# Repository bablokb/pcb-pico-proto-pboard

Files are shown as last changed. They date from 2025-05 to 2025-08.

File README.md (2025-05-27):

Protoyping Board for the Raspberry Pi Pico
==========================================

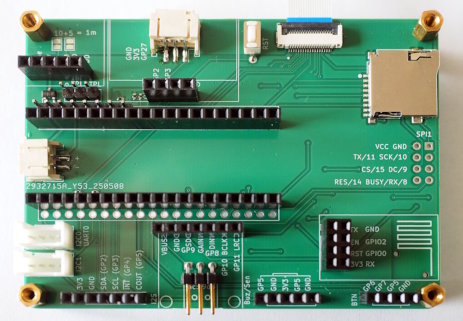
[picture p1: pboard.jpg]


This is a small prototyping board for the Pico. Besides
the normal 2x20 through holes for the Pico, the PCB also
provides additional sockets for the connection of peripherals.

The idea of this board is to simplify software-development
for standard breakouts, because it provides sockets for
these components and thus no wiring is necessary.

Some supported components:

  - Mini-I2C-OLED
  - EYESPI (typically for SPI-displays)
  - 2x Grove (I2C0/UART0 and I2C1)
  - ESP-01S or Lilygo T-01 C3
  - passive buzzer
  - MAX98357A (I2S mono-amplifier)
  - button-breakout (3xbutton, 1xGND)
  - RTC-socket (for this PCB: <https://github.com/bablokb/pcb-pico-pcf8563.git>)
  - Adafruit TPL5110 power-switch breakout
  - SD-card socket (on-board)
  - JST-PH2 battery connector
  - JST-PH3 connector (ADC)

Note that some components share pins, so it is *not possible* to use
all components in parallel! See [pinout](./pins.md) for details.

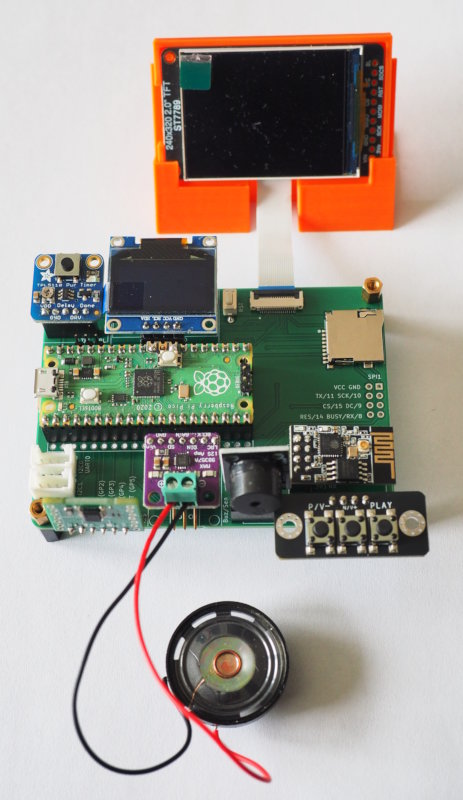
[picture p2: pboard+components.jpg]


Ready to use Gerber, BOM and POS files for JLCPCB are in the subdirectory
"production_files".

Schematic
---------

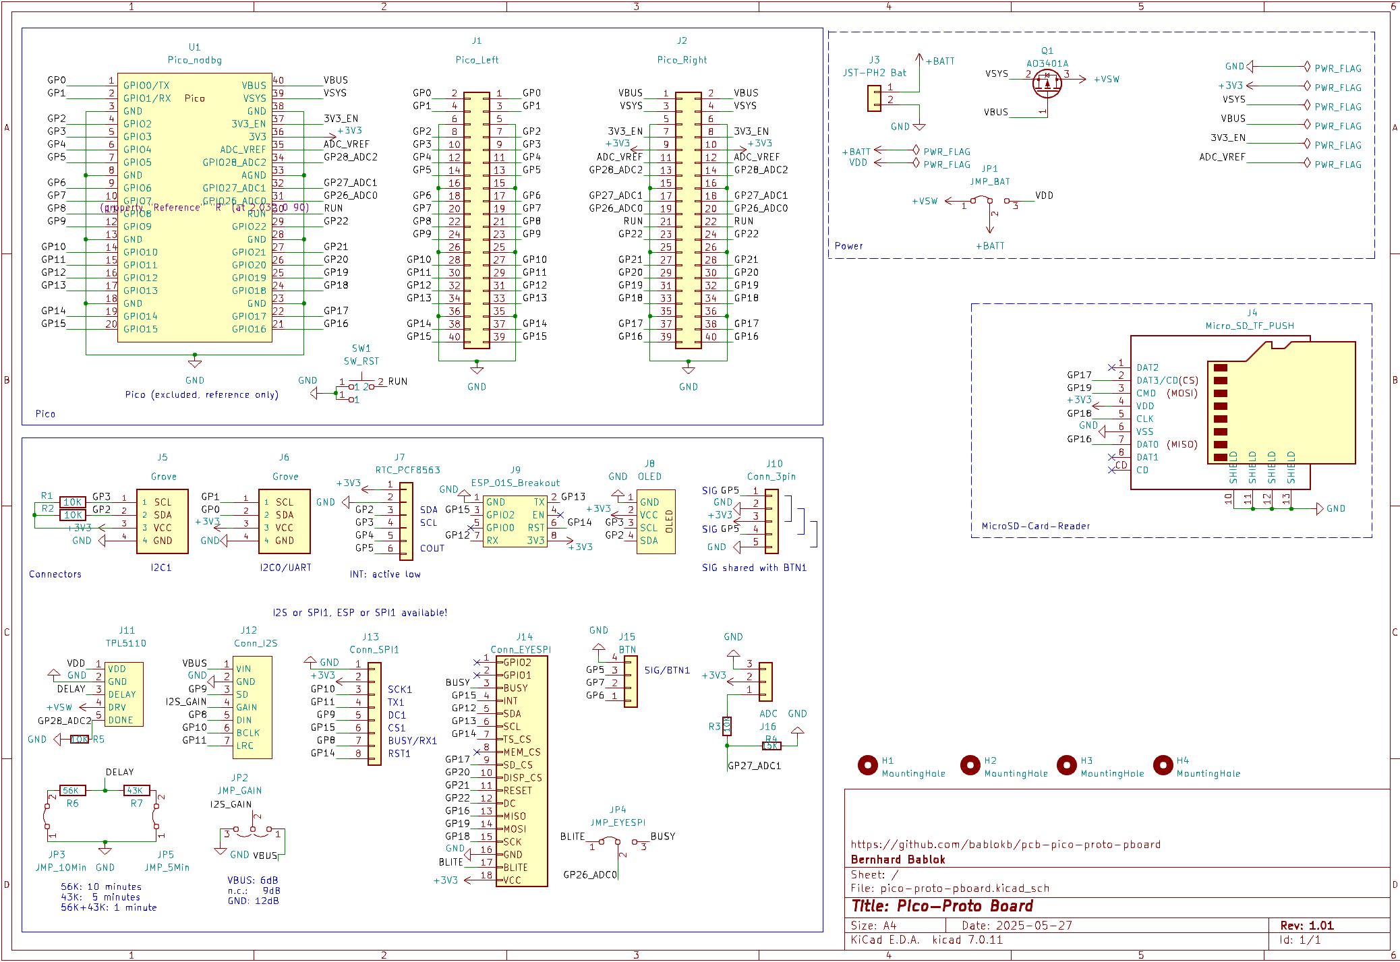
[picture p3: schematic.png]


Layout
------

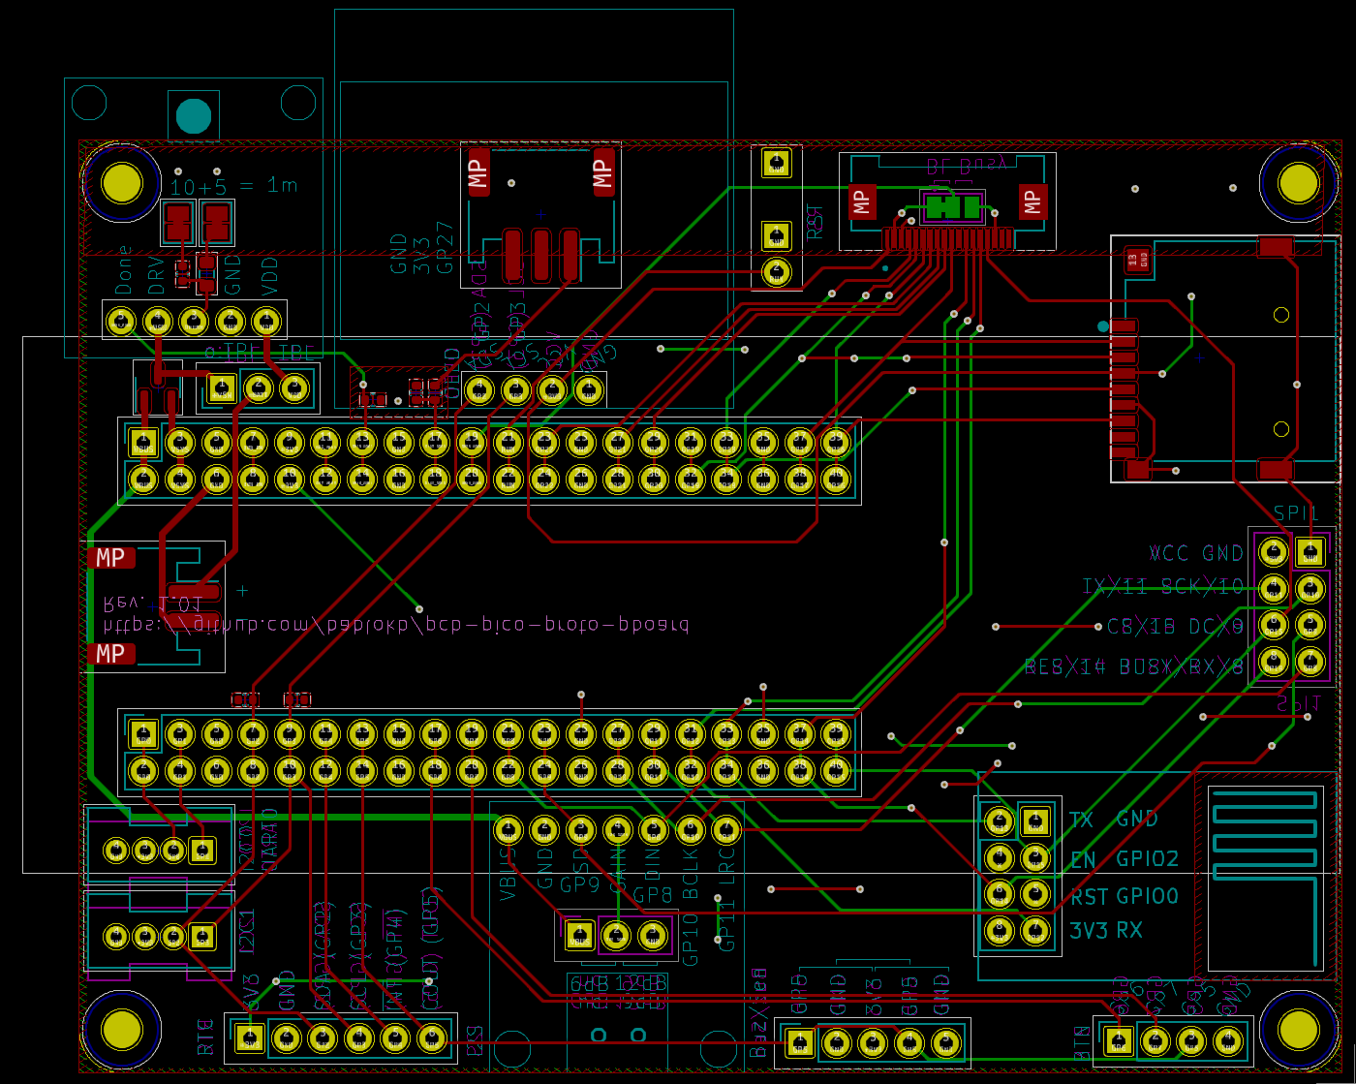
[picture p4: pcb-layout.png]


3D-Views
--------

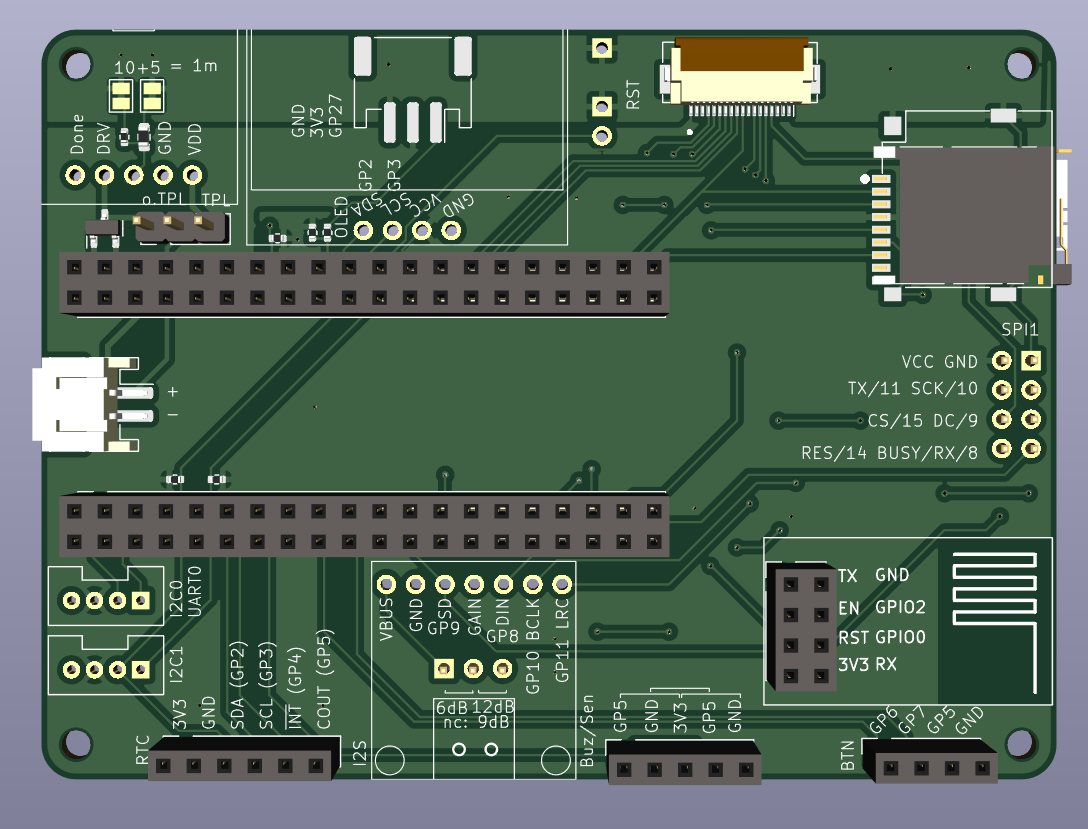
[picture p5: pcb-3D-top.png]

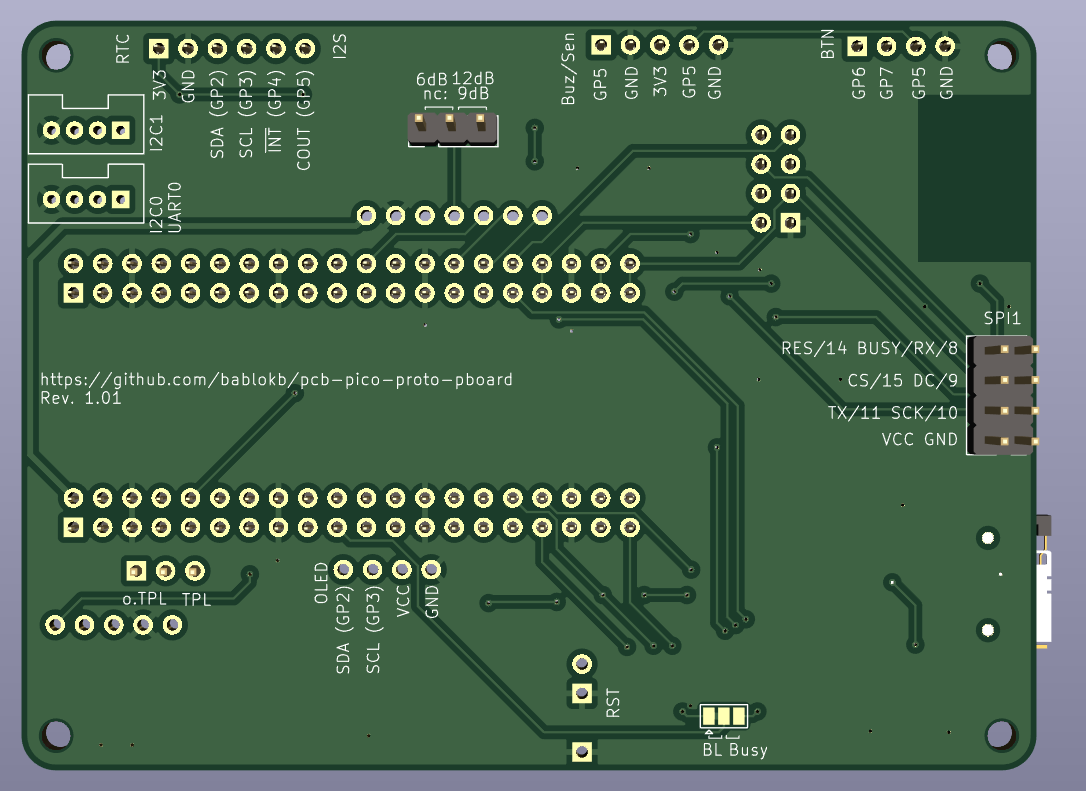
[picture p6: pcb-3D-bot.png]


License
-------

[![CC BY-SA 4.0][cc-by-sa-shield]][cc-by-sa]

This work is licensed under a
[Creative Commons Attribution-ShareAlike 4.0 International
License][cc-by-sa].

[][cc-by-sa]

[cc-by-sa]: http://creativecommons.org/licenses/by-sa/4.0/
[cc-by-sa-image]: https://licensebuttons.net/l/by-sa/4.0/88x31.png
[cc-by-sa-shield]:
https://img.shields.io/badge/License-CC%20BY--SA%204.0-lightgrey.svg

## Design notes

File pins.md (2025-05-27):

Pins
====

Pins on Raspberry Pi Pico
-------------------------

| | Pin  | Pin  | |
|---|---|---|---|
| TX0 | GP0  | VBUS |
| RX0 | GP1  | VSYS |
| | GND  | GND  |
| I2C1-SDA (RTC, I2C) | GP2  | EN |
| I2C1-SCL (RTC, I2C) | GP3  | 3V3  |
| RTC-INT | GP4  | VREF |
| COUT/SIG/BTN3 | GP5  | GP28 | TPL5110 DONE
| | GND  | GND  |
| BTN1 | GP6  | GP27 | ADC
| BTN2 | GP7  | GP26 | Display BL/Busy (EYESPI)
| MISO1/I2S_DATA/BSY1 | GP8  | RUN  | RUN
| DC1/I2S_MUTE | GP9  | GP22 | Display DC
| | GND  | GND  |
| SCK1/I2S_BLK | GP10 | GP21 | Display Reset (EYESPI)
| MOSI1/I2S_WSEL | GP11 | GP20 | Display CS (EYESPI)
| TX0 (ESP-01S-RX, | GP12 | GP19 | MOSI0 (EYESPI, SD-Card)
| EYESPI-SDA0) | | |
| RX0 (ESP-01S-TX, | GP13 | GP18 | SCLK0 (EYESPI, SD-Card)
| EYESPI-SCL0) | | |
| | GND  | GND  |
| RST-ESP01 (7)/RST1  | GP14 | GP17 | SD CS (EYESPI)
| EYESPI-TS_CS)  | | |
| IO2-ESP01 (2)/CS1 | GP15 | GP16 | MISO0 (EYESPI, SD-Card)
| EYESPI-INT) | | |

Pins on EYESPI
--------------

Use the onboard jumper-pad to select between
backlight and busy. TFT-displays use the backlight-pin while
e-paper displays use the busy-pin.

| Pin | Func | Mapped to
|-----|---|---|
| 1 | GPIO2 | n.c.
| 2 | GPIO1 | n.c.
| 3 | BUSY | GP26 (alternative)
| 4 | INT | GP15
| 5 | SDA | GP12
| 6 | SCL | GP13
| 7 | TS_CS | GP14
| 8 | MEM_CS  | n.c.
| 9 | SD_CS | GP17
|  10 | DISP_CS | GP20
|  11 | RESET | GP21
|  12 | DC | GP22
|  13 | MISO | GP16
|  14 | MOSI | GP19
|  15 | SCK | GP18
|  16 | GND | GND
|  17 | BLITE | GP26 (default)
|  18 | VCC | 3V3

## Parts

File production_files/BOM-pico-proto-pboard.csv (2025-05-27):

Comment | Designator | Footprint | LCSC
AO3401A | Q1 | SOT-23 | C15127
Conn_EYESPI | J14 | G-Shell-FPC_1x18_P0.50mm_Horizontal | C21260844
43K | R7 | R_0603_1608Metric | C23172
10K | R1,R2,R3,R5 | R_0402_1005Metric | C25744
15K | R4 | R_0402_1005Metric | C25756
56K | R6 | R_0402_1005Metric | C25796
Micro_SD_TF_PUSH | J4 | TF-Push | C393941

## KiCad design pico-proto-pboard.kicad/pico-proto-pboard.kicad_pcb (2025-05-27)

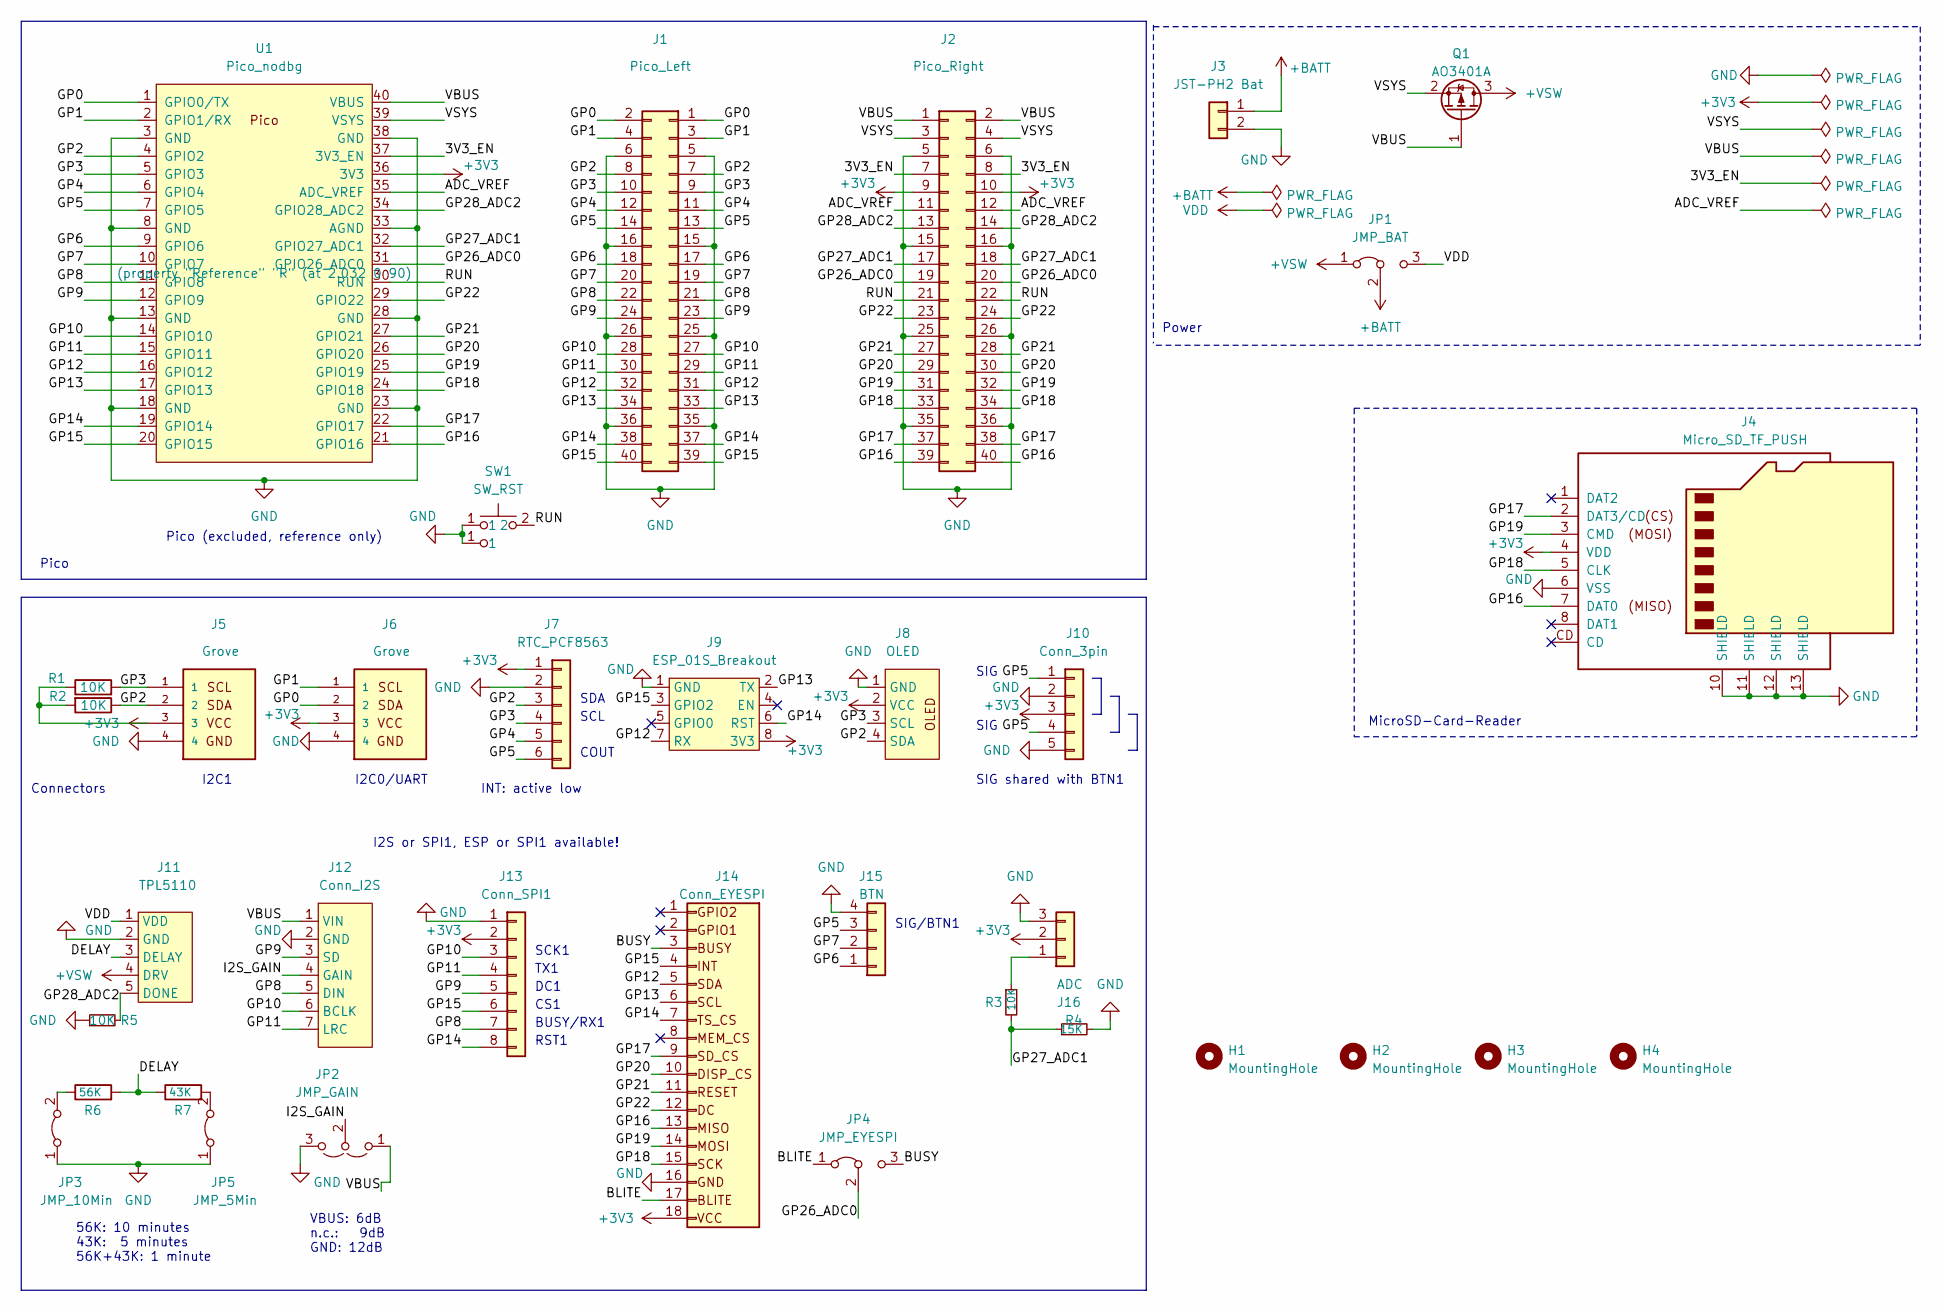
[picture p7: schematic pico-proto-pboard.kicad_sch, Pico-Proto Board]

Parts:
H1, H2, H3, H4: MountingHole; MountingHole_2.5mm
J1: Pico_Left; PinSocket_2x20_P2.54mm_Vertical
J2: Pico_Right; PinSocket_2x20_P2.54mm_Vertical
J3: JST-PH2 Bat; JST_PH_S2B-PH-SM4-TB_1x02-1MP_P2.00mm_Horizontal; LCSC C295747
J4: Micro_SD_TF_PUSH; TF-Push; LCSC C393941
J5, J6: Grove; grove_vertical
J7: RTC_PCF8563; PinSocket_1x06_P2.54mm_Vertical
J8: OLED; OLED_Display
J9: ESP_01S_Breakout
J10: Conn_3pin; PinSocket_1x05_P2.54mm_Vertical
J11: TPL5110; TPL5110_Breakout
J12: Conn_I2S; MAX98357A_Breakout
J13: Conn_SPI1; PinHeader_2x04_P2.54mm_Vertical
J14: Conn_EYESPI; G-Shell-FPC_1x18_P0.50mm_Horizontal; LCSC C21260844
J15: BTN; PinSocket_1x04_P2.54mm_Vertical
J16: ADC; JST_PH_S3B-PH-SM4-TB_1x03-1MP_P2.00mm_Horizontal
JP1: JMP_BAT; PinHeader_1x03_P2.54mm_Vertical
JP2: JMP_GAIN; PinHeader_1x03_P2.54mm_Vertical
JP3: JMP_10Min; SolderJumper-2_P1.3mm_Bridged_Pad1.0x1.5mm
JP4: JMP_EYESPI; SolderJumper-3_P1.3mm_Bridged12_Pad1.0x1.5mm
JP5: JMP_5Min; SolderJumper-2_P1.3mm_Bridged_Pad1.0x1.5mm
Q1: AO3401A; SOT-23; LCSC C15127
R1, R2, R3, R5: 10K; R_0402_1005Metric; LCSC C25744
R4: 15K; R_0402_1005Metric; LCSC C25756
R6: 56K; R_0402_1005Metric; LCSC C25796
R7: 43K; R_0603_1608Metric; LCSC C23172
SW1: SW_RST; SW_PUSH_SLIM_1x4
U1: Pico_nodbg; RPi_Pico_SMD_TH_nodbg; LCSC (property "Reference" "R" (at 2.032 0 9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

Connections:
+3V3: J2.9, J2.10, J4.4 (VDD), J5.3, J6.3, J7.1, J8.2 (VCC), J9.8 (3V3), J10.3, J13.2, J14.18, J16.2, R1.1, R2.2, U1.36 (3V3)
+BATT: J3.1, JP1.2 (C)
+VSW: J11.4 (DRV), JP1.1 (A), Q1.3 (D)
/3V3_EN: J2.7, J2.8, U1.37 (3V3_EN)
/ADC_VREF: J2.11, J2.12, U1.35 (ADC_VREF)
/BLITE: J14.17, JP4.1 (A)
/BUSY: J14.3, JP4.3 (B)
/DELAY: J11.3 (DELAY), R6.2, R7.1
/GP0: J1.1, J1.2, J6.2, U1.1 (GPIO0/TX)
/GP1: J1.3, J1.4, J6.1, U1.2 (GPIO1/RX)
/GP2: J1.7, J1.8, J5.2, J7.3, J8.4 (SDA), R2.1, U1.4 (GPIO2)
/GP3: J1.9, J1.10, J5.1, J7.4, J8.3 (SCL), R1.2, U1.5 (GPIO3)
/GP4: J1.11, J1.12, J7.5, U1.6 (GPIO4)
/GP5: J1.13, J1.14, J7.6, J10.1, J10.4, J15.3, U1.7 (GPIO5)
/GP6: J1.17, J1.18, J15.1, U1.9 (GPIO6)
/GP7: J1.19, J1.20, J15.2, U1.10 (GPIO7)
/GP8: J1.21, J1.22, J12.5 (DIN), J13.7, U1.11 (GPIO8)
/GP9: J1.23, J1.24, J12.3 (SD), J13.5, U1.12 (GPIO9)
/GP10: J1.27, J1.28, J12.6 (BCLK), J13.3, U1.14 (GPIO10)
/GP11: J1.29, J1.30, J12.7 (LRC), J13.4, U1.15 (GPIO11)
/GP12: J1.31, J1.32, J9.7 (RX), J14.5, U1.16 (GPIO12)
/GP13: J1.33, J1.34, J9.2 (TX), J14.6, U1.17 (GPIO13)
/GP14: J1.37, J1.38, J9.6 (RST), J13.8, J14.7, U1.19 (GPIO14)
/GP15: J1.39, J1.40, J9.3 (GPIO2), J13.6, J14.4, U1.20 (GPIO15)
/GP16: J2.39, J2.40, J4.7 (DAT0), J14.13, U1.21 (GPIO16)
/GP17: J2.37, J2.38, J4.2 (DAT3/CD), J14.9, U1.22 (GPIO17)
/GP18: J2.33, J2.34, J4.5 (CLK), J14.15, U1.24 (GPIO18)
/GP19: J2.31, J2.32, J4.3 (CMD), J14.14, U1.25 (GPIO19)
/GP20: J2.29, J2.30, J14.10, U1.26 (GPIO20)
/GP21: J2.27, J2.28, J14.11, U1.27 (GPIO21)
/GP22: J2.23, J2.24, J14.12, U1.29 (GPIO22)
/GP26_ADC0: J2.19, J2.20, JP4.2 (C), U1.31 (GPIO26_ADC0)
/GP27_ADC1: J2.17, J2.18, R3.2, R4.1, U1.32 (GPIO27_ADC1)
/GP28_ADC2: J2.13, J2.14, J11.5 (DONE), R5.2, U1.34 (GPIO28_ADC2)
/I2S_GAIN: J12.4 (GAIN), JP2.2 (C)
/RUN: J2.21, J2.22, SW1.2, U1.30 (RUN)
/VBUS: J2.1, J2.2, J12.1 (VIN), JP2.1 (A), Q1.1 (G), U1.40 (VBUS)
/VSYS: J2.3, J2.4, Q1.2 (S), U1.39 (VSYS)
GND: J1.5, J1.6, J1.15, J1.16, J1.25, J1.26, J1.35, J1.36, J2.5, J2.6, J2.15, J2.16, J2.25, J2.26, J2.35, J2.36, J3.2, J4.6 (VSS), J4.10 (SHIELD), J4.11 (SHIELD), J4.12 (SHIELD), J4.13 (SHIELD), J5.4, J6.4, J7.2, J8.1 (GND), J9.1 (GND), J10.2, J10.5, J11.2 (GND), J12.2 (GND), J13.1, J14.16, J15.4, J16.3, JP2.3 (B), JP3.1 (A), JP5.1 (A), R4.2, R5.1, SW1.1, U1.3 (GND), U1.8 (GND), U1.13 (GND), U1.18 (GND), U1.23 (GND), U1.28 (GND), U1.33 (AGND), U1.38 (GND)
unnamed: J16.1, R3.1
unnamed: JP3.2 (B), R6.1
unnamed: JP5.2 (B), R7.2
VDD: J11.1 (VDD), JP1.3 (B)

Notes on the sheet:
SIG
TX1
56K: 10 minutes 43K: 5 minutes 56K+43K: 1 minute
SDA
Pico (excluded, reference only)
DC1
CS1
SCK1
I2S or SPI1, ESP or SPI1 available!
INT: active low
Pico
SCL
Power
MicroSD-Card-Reader
SIG shared with BTN1
BUSY/RX1
SIG/BTN1
Connectors
RST1
VBUS: 6dB n.c.: 9dB GND: 12dB
I2C0/UART
I2C1
COUT

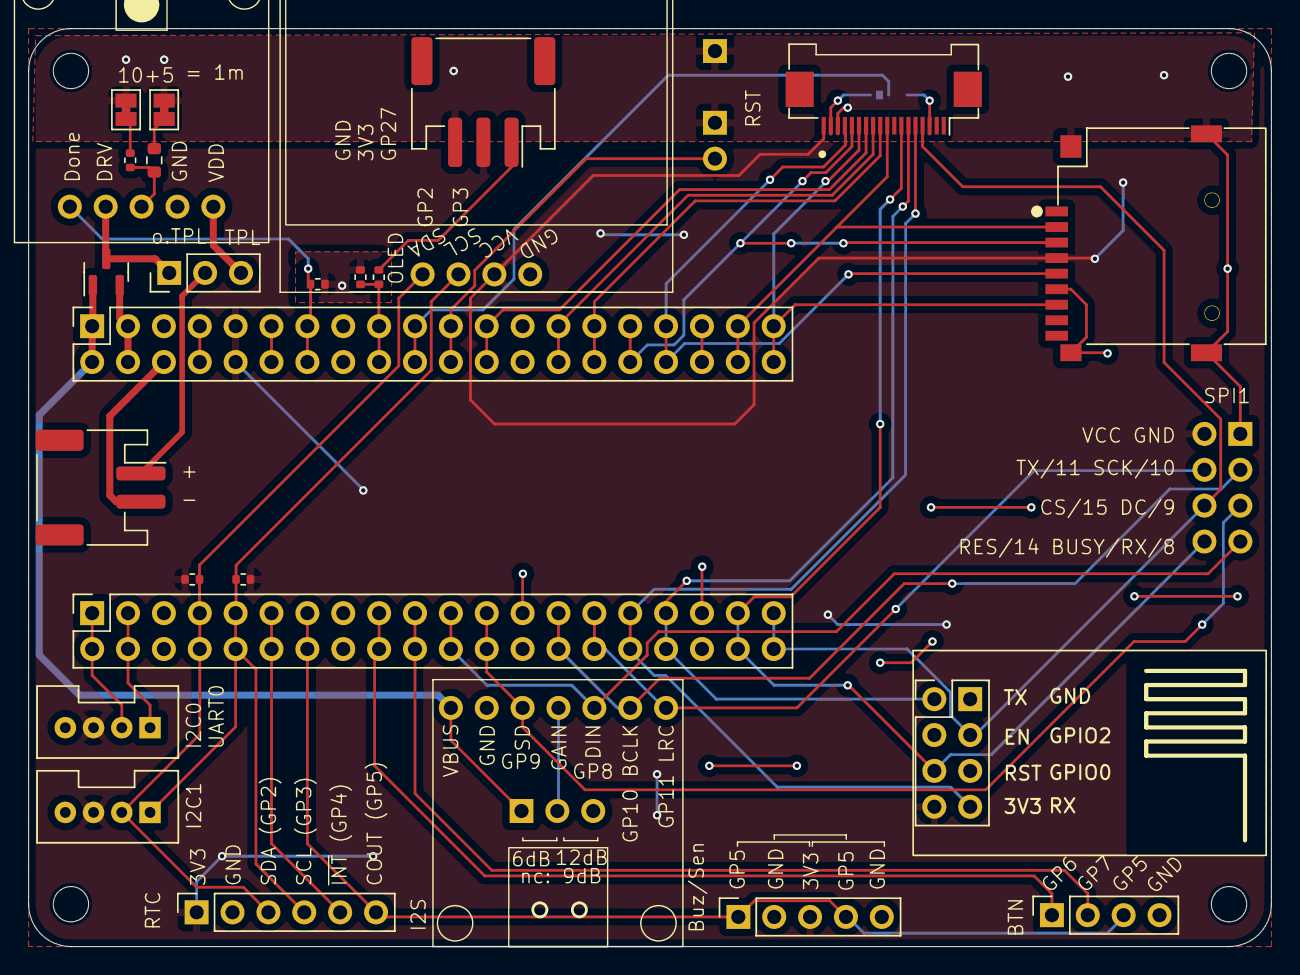
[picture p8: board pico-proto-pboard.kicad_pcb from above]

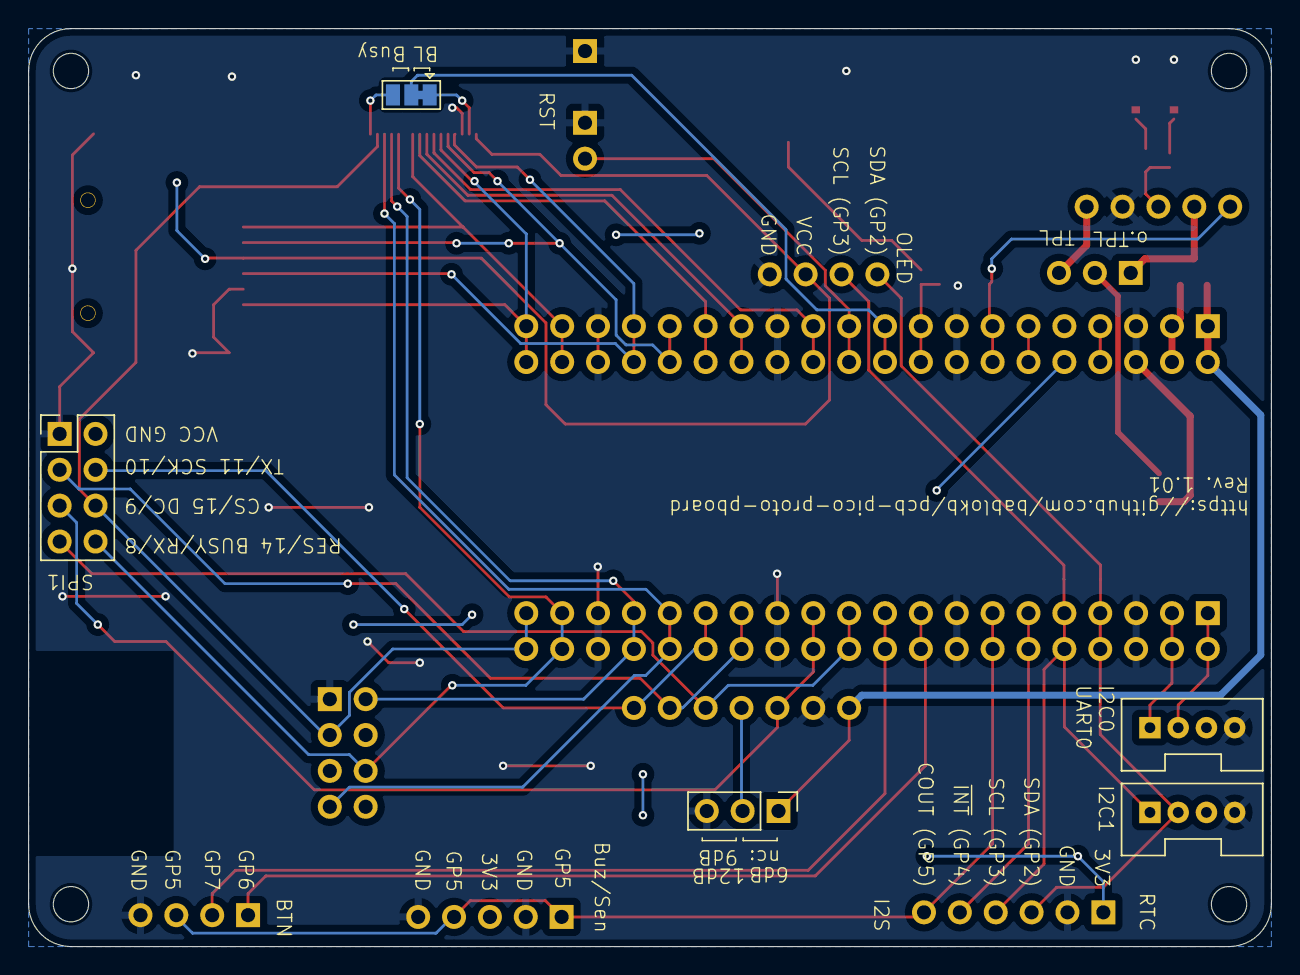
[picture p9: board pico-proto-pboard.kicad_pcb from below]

Board: 2 copper layers, 88.0 x 65.0 mm, 34 parts (3 on the bottom side), 43 nets.

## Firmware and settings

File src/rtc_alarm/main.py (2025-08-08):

# ----------------------------------------------------------------------------
# Deep-Sleep with RTC wake up.
#
# Author: Bernhard Bablok
# License: GPL3
#
# Website: https://github.com/bablokb/pcb-pico-proto-bb
# ----------------------------------------------------------------------------

import alarm
import atexit
import board
import busio
import digitalio
import rtc
import microcontroller
import socketpool
import time
import wifi

import displayio
import terminalio
import adafruit_requests
from adafruit_display_text import label
from adafruit_bitmap_font import bitmap_font

from pboard import pboard
from pboard import helpers
from secrets import secrets

USE_OLED = True
SLEEP_TIME = 50
WORK_TIME = 10
DEBUG = False
TX_POWER = 15

# --- initialize co-processor    ---------------------------------------------

def init_coprocessor():
  """ initialize co-processor """

  uart = busio.UART(pboard.ESP_TX, pboard.ESP_RX, baudrate=115200,
                    receiver_buffer_size=2048)
  rc = wifi.init(uart,debug=DEBUG,reset_pin=pboard.ESP_RST)
  if not rc:
    raise RuntimeError("could not setup co-processor")
  wifi.radio.start_station()
  wifi.radio.tx_power = TX_POWER

# --- query local time from time-server   ---------------------------------

def get_remote_time():
  """ query time from time-server """

  pool = socketpool.SocketPool(wifi.radio)
  requests = adafruit_requests.Session(pool)

  response = requests.get(secrets['time_api_url']).json()

  if 'struct_time' in response:
    return time.struct_time(tuple(response['struct_time']))

  current_time = response["datetime"]
  the_date, the_time = current_time.split("T")
  year, month, mday = [int(x) for x in the_date.split("-")]
  the_time = the_time.split(".")[0]
  hours, minutes, seconds = [int(x) for x in the_time.split(":")]

  year_day = int(response["day_of_year"])
  week_day = int(response["day_of_week"])
  week_day = 6 if week_day == 0 else week_day-1
  is_dst   = int(response["dst"])

  return time.struct_time(
    (year, month, mday, hours, minutes, seconds, week_day, year_day, is_dst))

# --- connect and update RTC   -----------------------------------------------

def update_rtc(ext_rtc):
  """ update RTC """
  helpers.connect()
  ts = get_remote_time()
  ext_rtc.datetime = ts
  int_rtc = rtc.RTC()
  int_rtc.datetime = ts

# --- atexit processing   ----------------------------------------------------

def at_exit(i2c):
  """ release i2c """
  print(f"releasing {i2c}")
  i2c.deinit()

# --- main program   ---------------------------------------------------------

#helpers.wait_for_console()

# setup board LED
led = digitalio.DigitalInOut(board.LED)
led.direction = digitalio.Direction.OUTPUT
led.value = False

# check reset reason
rr_reason = (f"{microcontroller.cpu.reset_reason}").split(".")[-1]
print(f"reset reason: {rr_reason}")

# fetch time and update RTC
ext_rtc = pboard.rtc()
if rr_reason == "POWER_ON":
  print("updating RTC")
  init_coprocessor()
  update_rtc(ext_rtc)
else:
  # assume time is valid
  print("clearing alarm")
  ext_rtc.alarm_status = False
  ext_rtc.alarm_interrupt = False
  ts = ext_rtc.datetime
  rtc.RTC().datetime = ts

# release I2C1 at exit (allocated by rtc)
atexit.register(at_exit,pboard.i2c1())
atexit.register(displayio.release_displays)

# create display
displayio.release_displays()
if USE_OLED:
  display = pboard.oled_display(rotation=180)
else:
  display = pboard.eyespi_display()        # use default display

# create labels
# upper boarder: reset-reason
pos = helpers.pos_map(display)['N']
txt_reason = label.Label(terminalio.FONT,text=rr_reason,color=0xFFFFFF,
                       anchor_point=pos[0])
txt_reason.anchored_position = pos[1]

# center: time
pos = helpers.pos_map(display)['C']
font = bitmap_font.load_font("fonts/DejaVuSans-Bold-24-min.bdf")
txt_time = label.Label(font,text='00:00:00',color=0xFFFFFF,
                       anchor_point=pos[0])
txt_time.anchored_position = pos[1]

# lower boarder: state
pos = helpers.pos_map(display)['S']
txt_state = label.Label(terminalio.FONT,text='active',color=0xFFFFFF,
                        anchor_point=pos[0])
txt_state.anchored_position = pos[1]

# create and set root-group
group = displayio.Group()
group.append(txt_reason)
group.append(txt_time)
group.append(txt_state)
display.root_group = group

# do some work
for _ in range(WORK_TIME):
  now = time.localtime()
  txt_time.text = f"{now.tm_hour:02d}:{now.tm_min:02d}:{now.tm_sec:02d}"
  for __ in range(4):
    time.sleep(0.125)
    led.value = not led.value
    time.sleep(0.125)
    led.value = not led.value

# switch display
txt_state.text = "sleep"
time.sleep(1)

# set wake up time and create pin-alarm
alarm_time = time.mktime(now) + SLEEP_TIME
print(f"deep-sleep for {SLEEP_TIME} seconds")
pin_alarm = alarm.pin.PinAlarm(pboard.RTC_INT,
                               value=False,edge=True,pull=True)
ext_rtc.alarm  = (time.localtime(alarm_time),"daily")
ext_rtc.alarm_interrupt = True

alarm.exit_and_deep_sleep_until_alarms(pin_alarm)

time.sleep(1)
print("we should not be here!")

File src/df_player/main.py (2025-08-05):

# ----------------------------------------------------------------------------
# Play music using an UART attached DFPlayer Mini.
#
# Needs the DFPlayer library from:
#   https://github.com/bablokb/circuitpython-dfplayer
#
# Author: Bernhard Bablok
# License: GPL3
#
# Website: https://github.com/bablokb/pcb-pico-proto-bb
# ----------------------------------------------------------------------------

import board
import digitalio
import time
import busio

from pboard import pboard
from pboard import helpers
from DFPlayer import DFPlayer

# --- main program   ---------------------------------------------------------

helpers.wait_for_console()

uart = pboard.uart0(gp01=True,baudrate=9600)
player = DFPlayer(uart)

led = digitalio.DigitalInOut(board.LED)
led.direction = digitalio.Direction.OUTPUT
led.value = True

print(f"playing...")
player.play()

while True:
  time.sleep(0.2)
  led.value = False
  time.sleep(0.2)
  led.value = True

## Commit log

2025-07-02 add support for I2S-breakout incl. mute-pin
2025-07-02 fix: wait_for_console(): add missing 'import time'
    [helpers.py]
2025-07-14 added ESP32 co-processor example
2025-07-15 added sensor-button example
2025-07-17 fix problems with deep-sleep
    [main.py]
2025-08-05 uart0(): add baudrate as parameter
